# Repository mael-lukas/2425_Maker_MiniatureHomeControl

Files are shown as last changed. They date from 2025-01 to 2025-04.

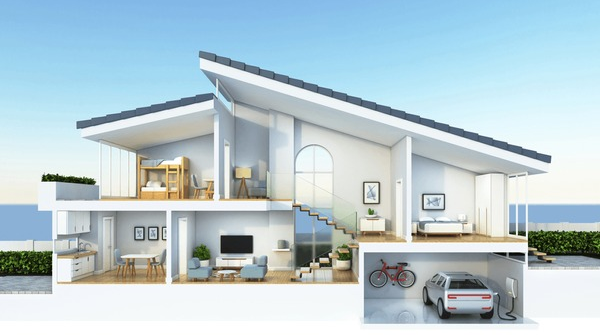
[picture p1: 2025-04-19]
Media/Design Inspirations/screen2.png

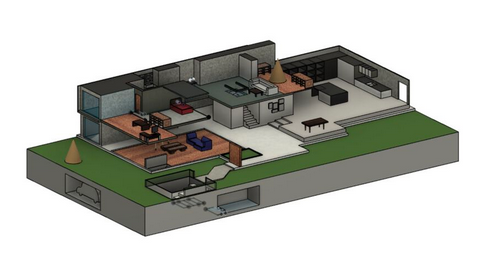
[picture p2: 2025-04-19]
Media/Design Inspirations/screen1.png

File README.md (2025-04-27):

Miniature Home control

Maker 2024-2025 - Miniature Home control
========================================

Project overview

Introduction
------------

This project was carried out as part of the Maker option at ENSEA. The idea was to create a miniature home that could house a small animal with a bunch of actuated parts  
(doors, lights, food dispenser...) that could be activated remotely.  
Design-wise the house is inspired by typical doll house designs and modern houses:



Below is the architectural diagram that sums up all the features that were to be included in the house at the start of the project:

CAD
---

This project involved a lot of CAD. A significant part was the modeling of the whole house. The goal was to make the house out of wood using the laser cutter.  
Thus the model needed to be able to be separated in several parts to be cut on a flat sheet



All the furnitures to be placed in the house were also 3D modeled by myself (except the chair I downloaded it online). They were then 3D printed.



PCB
---

Every PCBs in this project were designed on KiCAD and manufactured by JLCPCB.  
This project needed two PCBs: one main unit would be wired to every actuatable parts in the house.  
Thus, it is mainly comprised of sockets to wire to every motors, lights, TV...



The second PCB is the controller of the house to actuate remotely every part of the house. Thus it is mainly comprised of buttons to look like a run-of-the-mill remote:



Assembly
--------

After laser cutting the wood the house was assembled, some furnitures were also placed inside:



The assembly part also involved a lot of wiring. I made custom wires for the power supply to power the main unit, a LiPo battery for the controller  
and several wires for motors and lights in the house:



Programming
-----------

The code was written  in C language on STM32 CubeIDE. It is devised according to this diagram:



I wrote a working code for the LCD screen (for the TV), servo motors, Neopixel LEDs and the MP3 module. I did not have time to test the code for the HC-05 bluetooth module.  
The whole code can be found in the GitHub repository (as well as every other resources of the project)

Final word
----------

I did not have the time to finish the project so only the house, the PCBs and the lights and doors are implemented but I still had a great time doing this project and participating in Maker.

### Short video

Here is a short [video](https://www.youtube.com/watch?v=WIeOZKU2mvY&t=1s) (in French) to sum up the project and my views on the Maker option

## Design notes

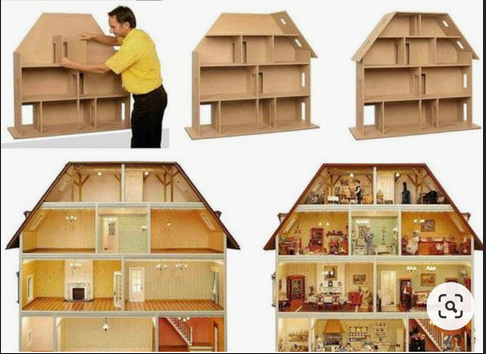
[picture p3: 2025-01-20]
Media/Design Inspirations/screen.png

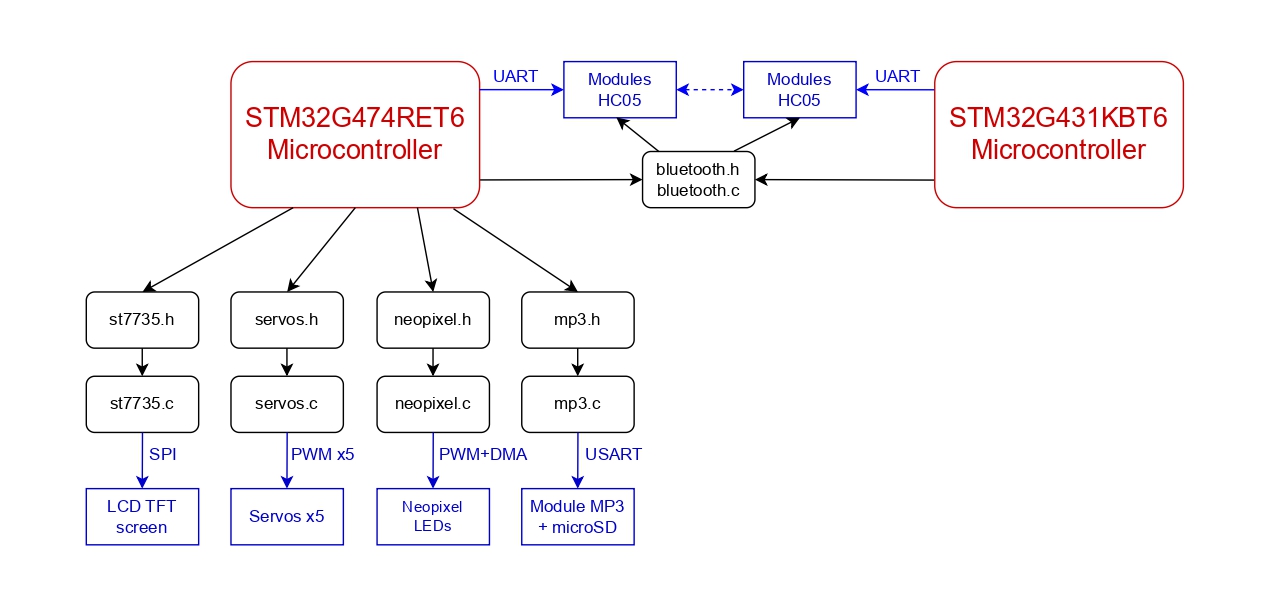
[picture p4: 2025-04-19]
Project Management/code architecture.jpg

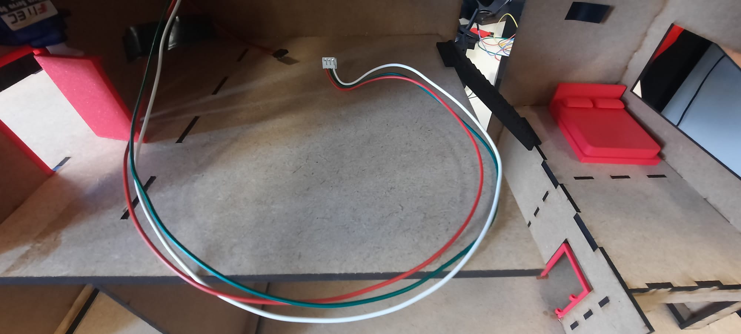
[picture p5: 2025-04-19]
Media/Project pictures/pic12.jpeg

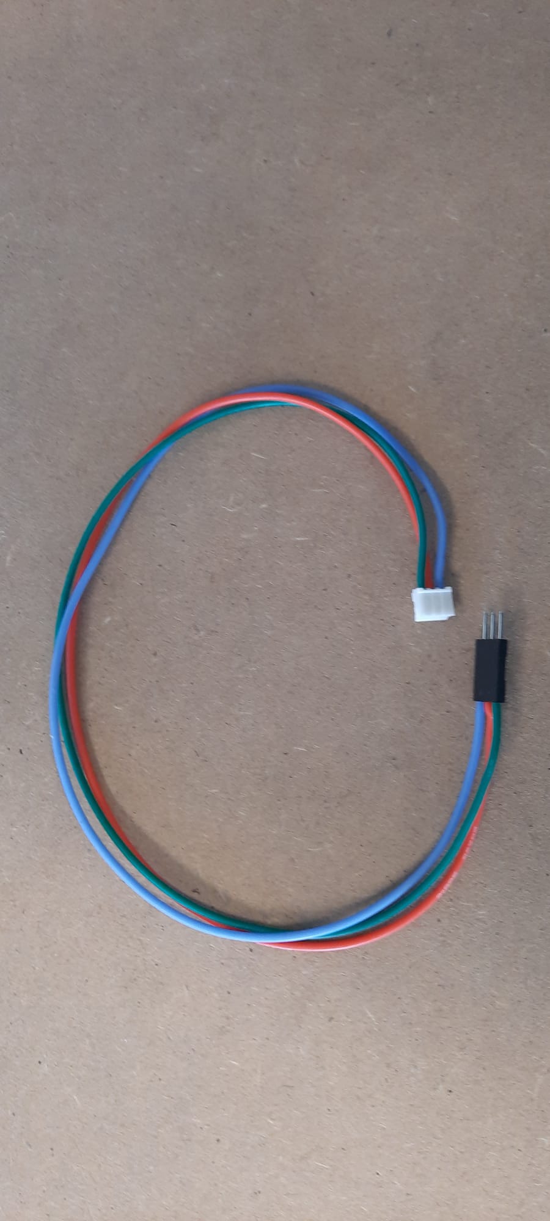
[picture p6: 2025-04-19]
Media/Project pictures/pic1.jpeg

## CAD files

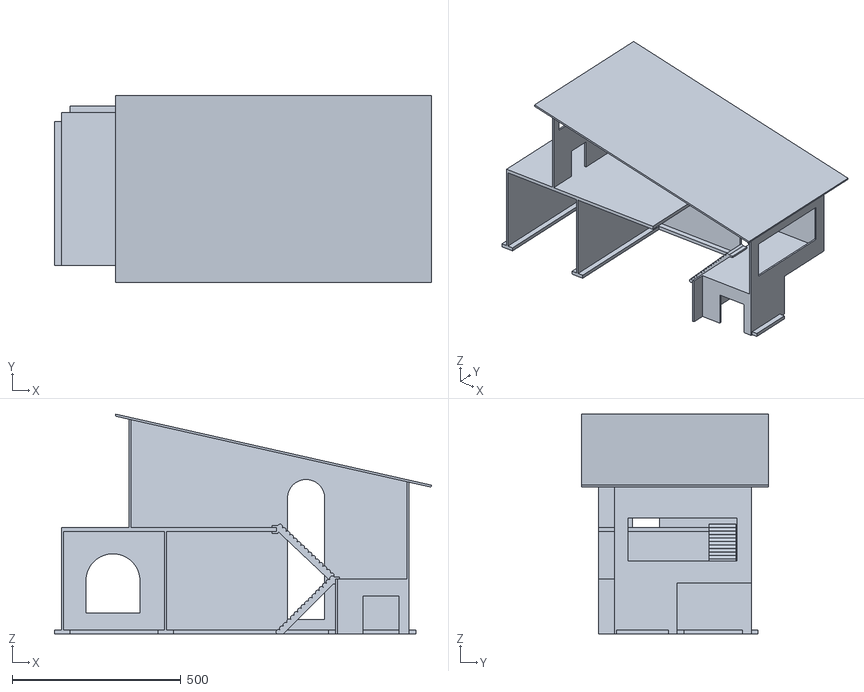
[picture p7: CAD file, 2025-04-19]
CAD/full_house.stl
1116.3 x 553.0 x 650.6

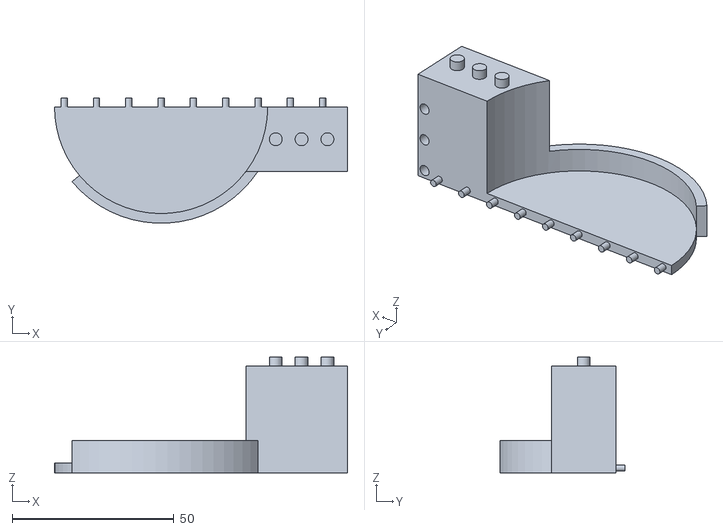
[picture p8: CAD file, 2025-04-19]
CAD/food_5.stl
90.7 x 38.8 x 35.8

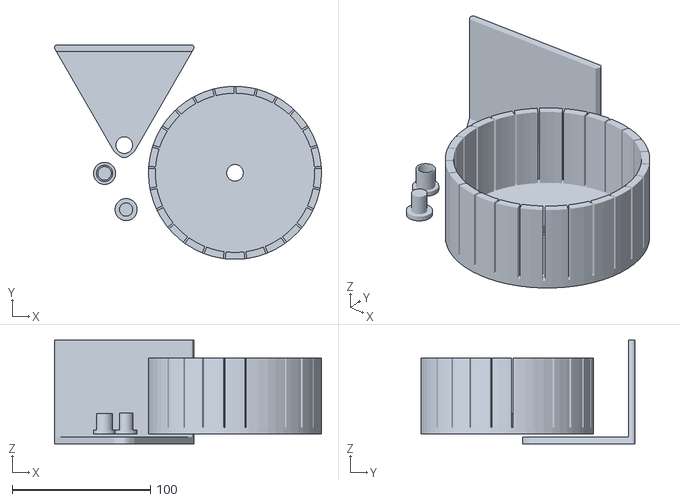
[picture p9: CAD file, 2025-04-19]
CAD/wheel.stl
192.9 x 154.9 x 75.0

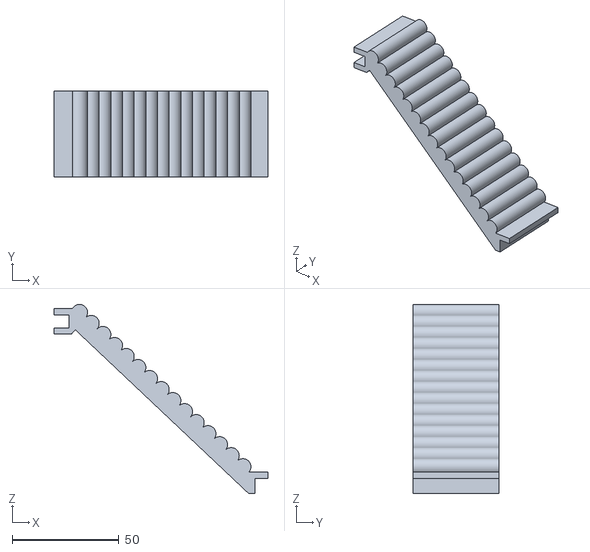
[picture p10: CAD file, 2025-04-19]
CAD/stairs_2.stl
100.0 x 40.0 x 88.4

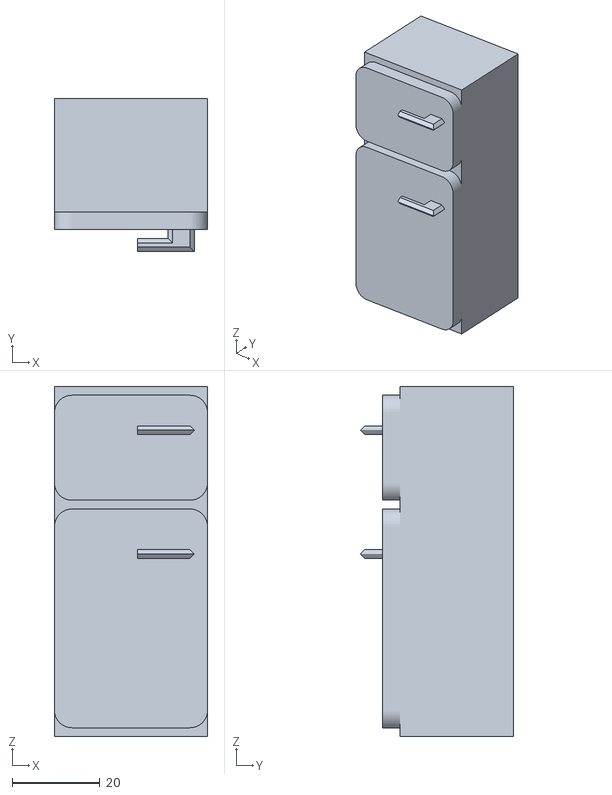
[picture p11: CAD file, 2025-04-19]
CAD/refridgator.stl
35.0 x 35.0 x 80.0

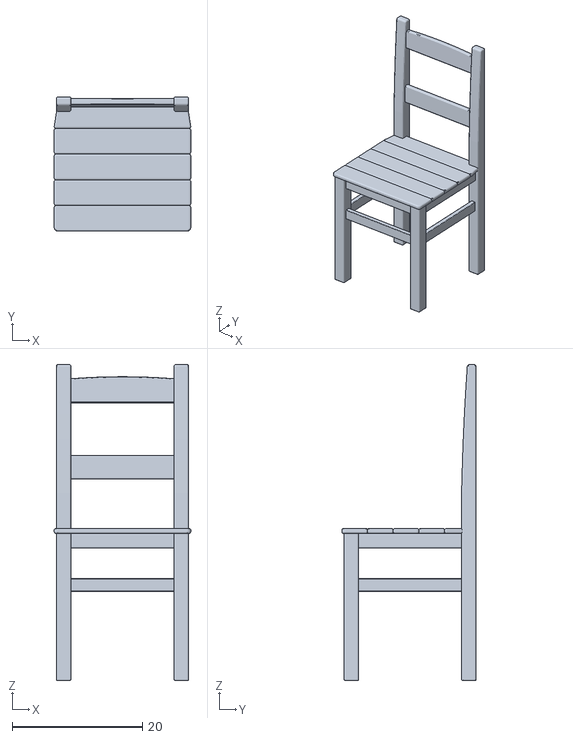
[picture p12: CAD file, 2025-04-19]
CAD/chair.stl
21.0 x 20.7 x 48.5

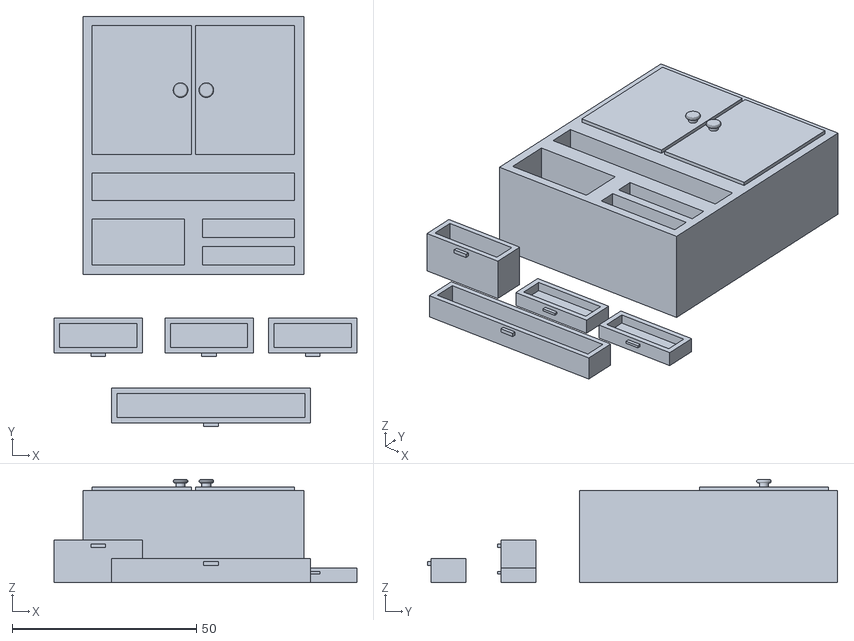
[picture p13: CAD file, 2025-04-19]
CAD/wardrobe.stl
82.2 x 111.3 x 28.0

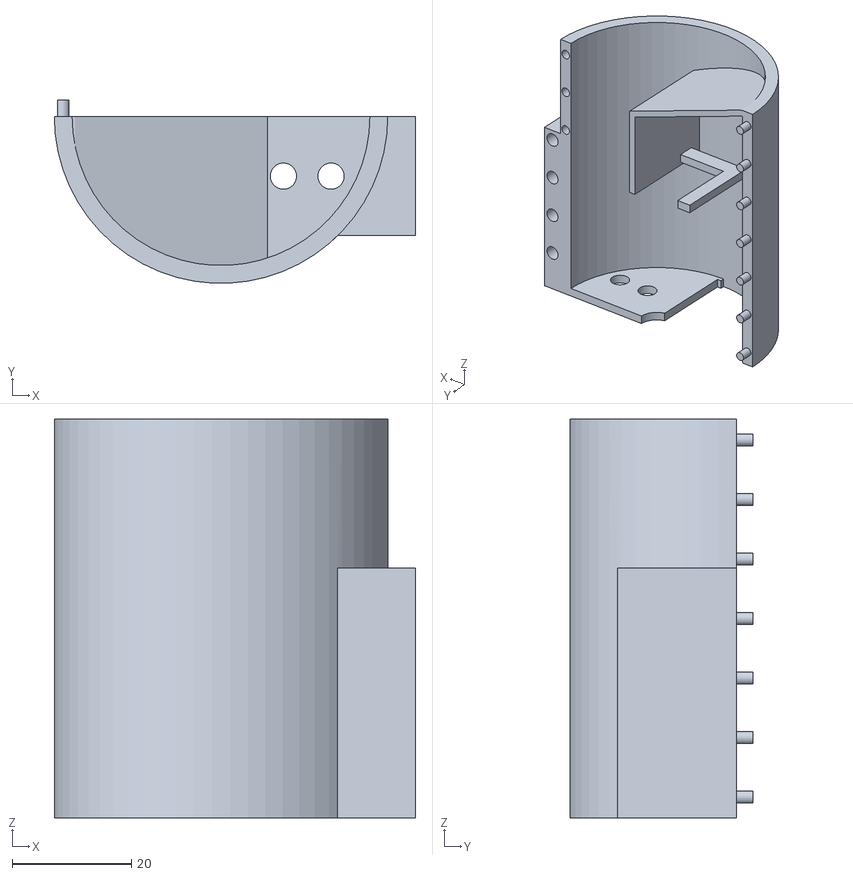
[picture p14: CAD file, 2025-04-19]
CAD/food_1.stl
60.7 x 30.8 x 67.0

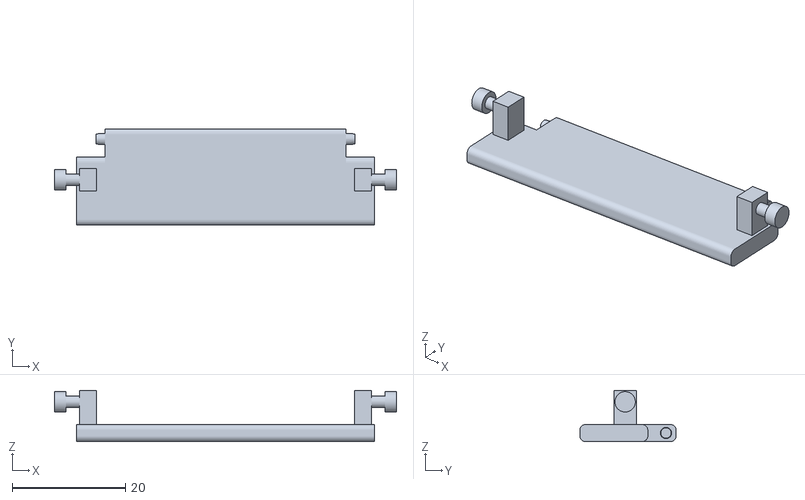
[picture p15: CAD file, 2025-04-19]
CAD/gdoor_2.stl
60.3 x 17.0 x 9.00

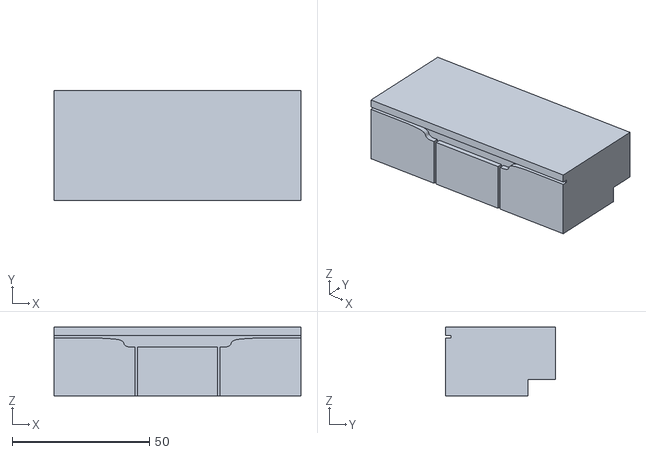
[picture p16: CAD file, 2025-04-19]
CAD/tv_drawer.stl
90.0 x 40.0 x 25.0

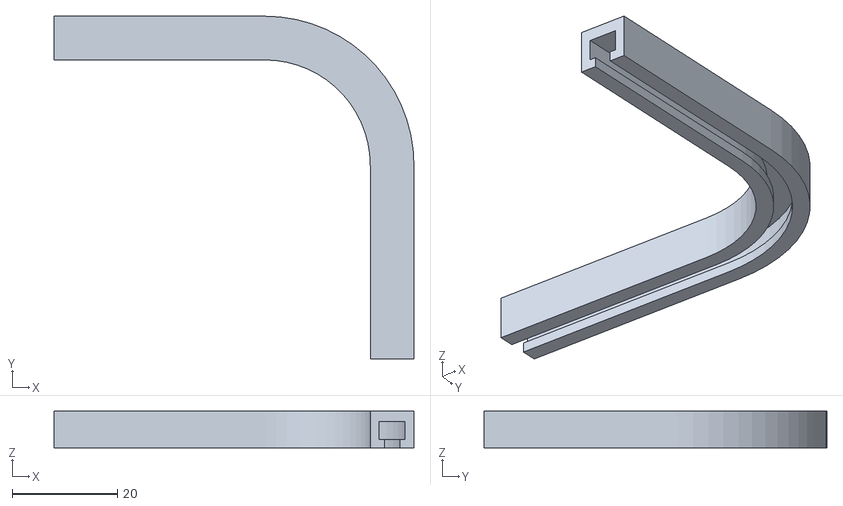
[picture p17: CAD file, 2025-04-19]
CAD/rail_2.stl
68.3 x 65.0 x 7.00

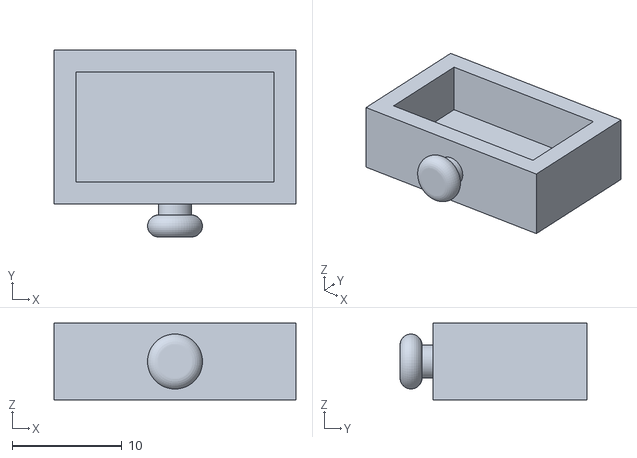
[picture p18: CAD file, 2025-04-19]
CAD/drawer_2.stl
22.0 x 17.0 x 7.00

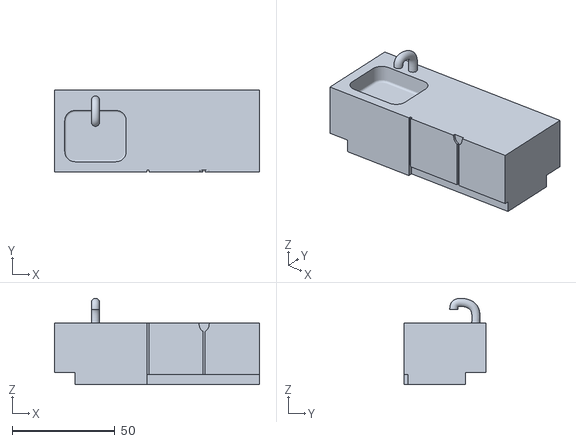
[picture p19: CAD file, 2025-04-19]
CAD/sink.stl
100.0 x 40.0 x 42.2

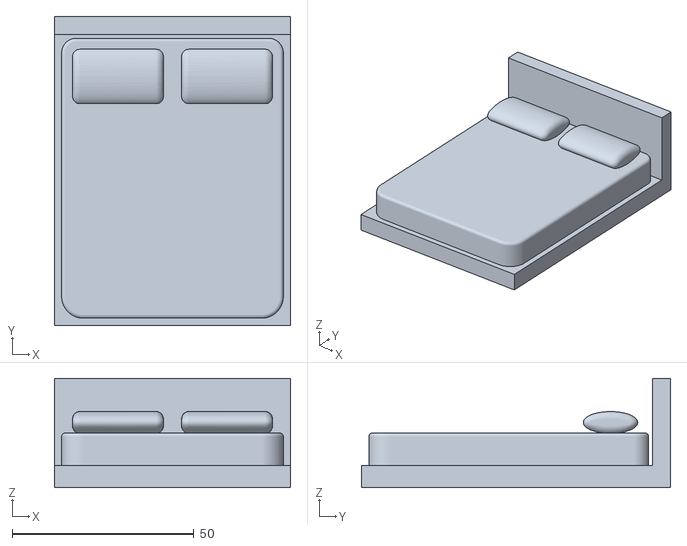
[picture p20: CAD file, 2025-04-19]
CAD/bed.stl
65.0 x 85.0 x 30.0

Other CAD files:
CAD/food_3.stl
CAD/door_1.stl
CAD/food_2.stl
CAD/gdoor_3.stl
CAD/door_2.stl
CAD/drawer_1.stl
CAD/food_4.stl
CAD/gdoor_1.stl
CAD/rail_1.stl
CAD/stairs_1.stl
CAD/table.stl

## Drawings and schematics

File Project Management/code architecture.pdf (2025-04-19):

## STM32G474RET6 Microcontroller

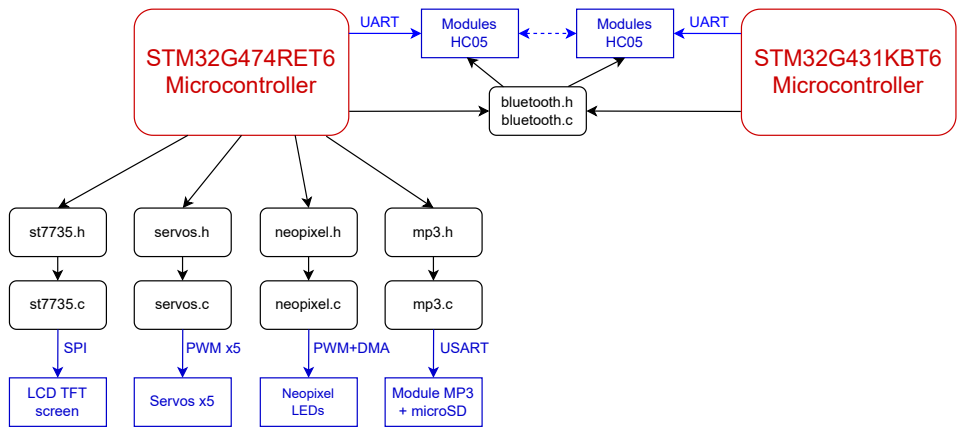
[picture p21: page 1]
LCD TFT screen; servos.h; servos.c; Servos x5; neopixel.h; neopixel.c; Neopixel LEDs; Module MP3 + microSD; SPI; PWM x5; PWM+DMA; USART; STM32G431KBT6 Microcontroller; Modules HC05; bluetooth.h bluetooth.c; UART

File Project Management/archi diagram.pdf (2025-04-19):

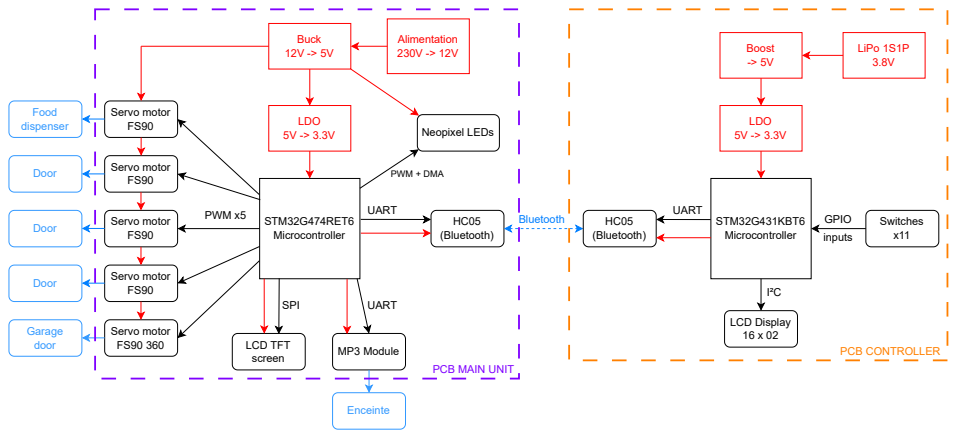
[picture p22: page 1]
STM32G474RET6 Microcontroller; Alimentation 230V -> 12V; Buck 12V -> 5V; LDO 5V -> 3.3V; Servo motor FS90; Servo motor FS90 360; LCD TFT screen; Neopixel LEDs; MP3 Module; Enceinte; HC05 (Bluetooth); PWM x5; PWM + DMA; SPI; UART; Food dispenser; Door; Garage door; Bluetooth; STM32G431KBT6; Microcontroller; LiPo 1S1P 3.8V; Boost -> 5V; Switches x11; GPIO; inputs; LCD Display 16 x 02; I²C; PCB CONTROLLER

PCB MAIN UNIT

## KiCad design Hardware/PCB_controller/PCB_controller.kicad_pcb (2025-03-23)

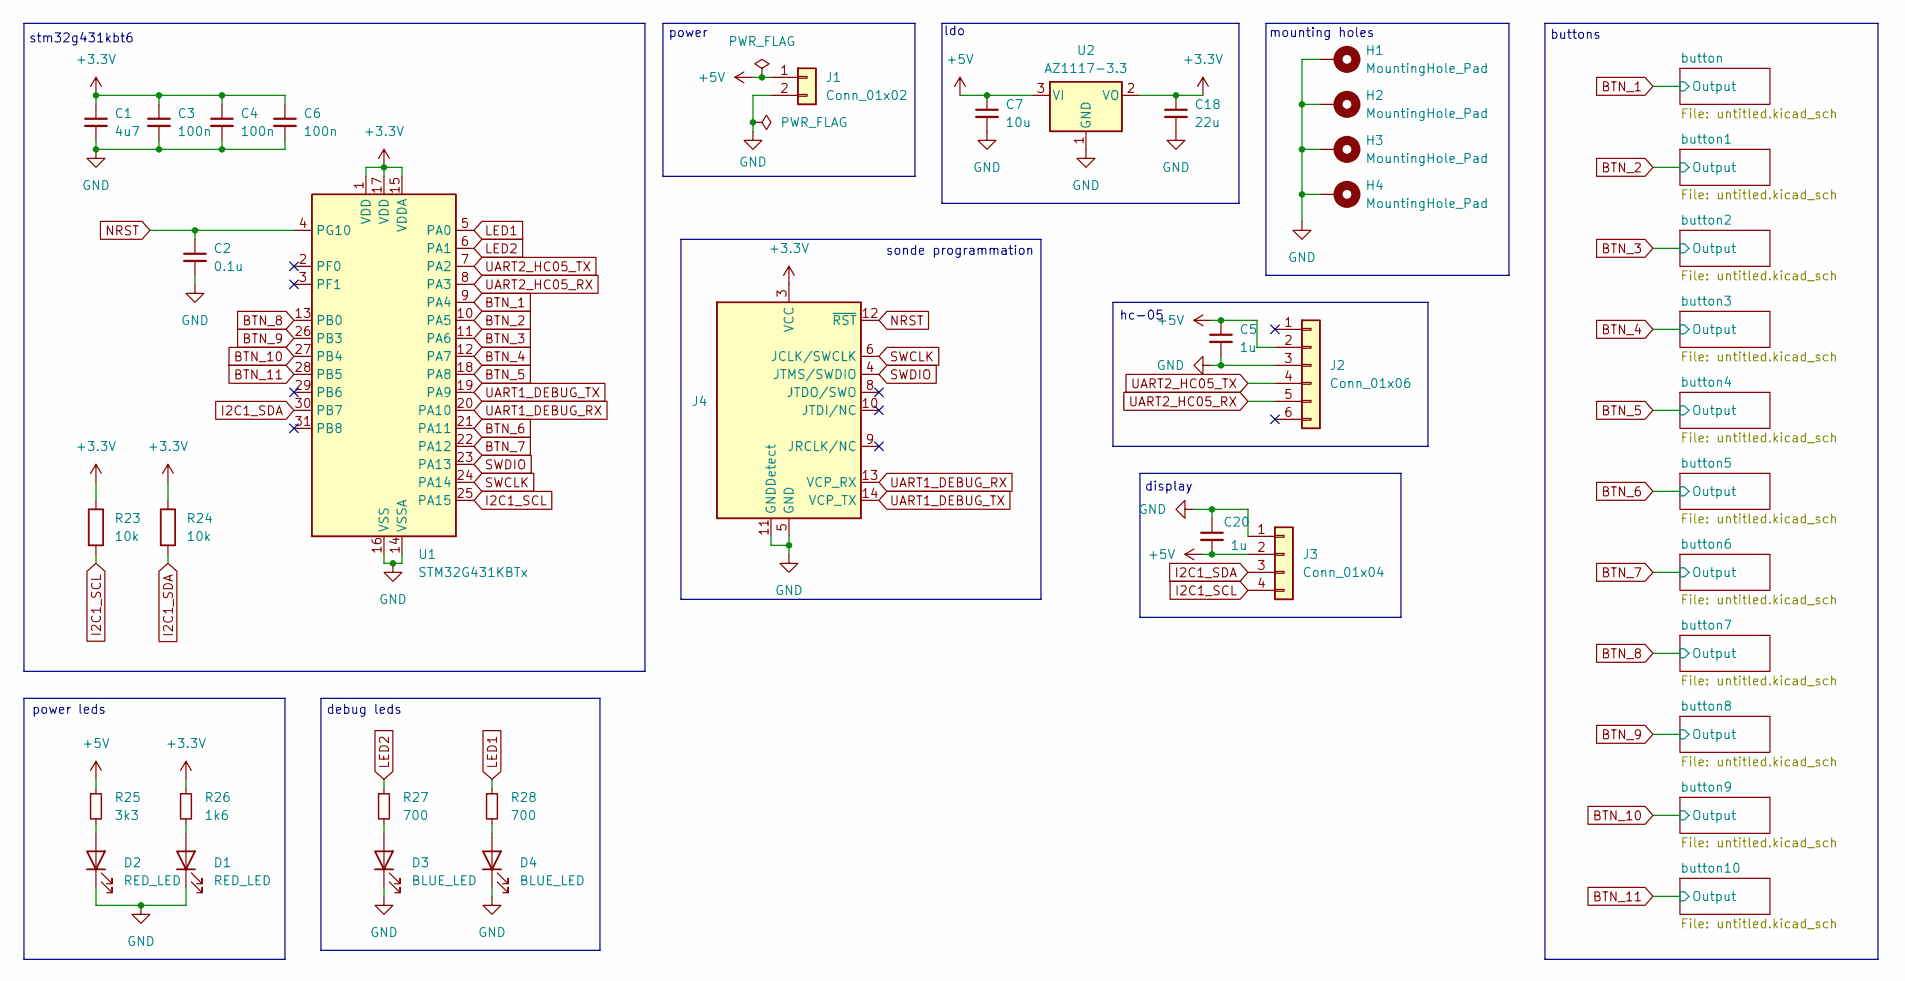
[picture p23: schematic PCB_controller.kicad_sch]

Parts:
C1: 4u7; C_0603_1608Metric
C2: 0.1u; C_0402_1005Metric_Pad0.74x0.62mm_HandSolder
C3, C4, C6: 100n; C_0402_1005Metric_Pad0.74x0.62mm_HandSolder
C5, C20: 1u; C_0603_1608Metric
C7: 10u; C_0603_1608Metric
C18: 22u; C_Elec_5x5.4
D1, D2: RED_LED; LED_0603_1608Metric; MPN 150060RS55040
D3, D4: BLUE_LED; LED_0603_1608Metric; MPN 150060BS55040
H1, H2, H3, H4: MountingHole_Pad; MountingHole_3.2mm_M3_Pad_Via
J1: Conn_01x02; JST_EH_B2B-EH-A_1x02_P2.50mm_Vertical
J2: Conn_01x06; JST_EH_B6B-EH-A_1x06_P2.50mm_Vertical
J3: Conn_01x04; JST_EH_B4B-EH-A_1x04_P2.50mm_Vertical
J4: Conn_ST_STDC14; PinHeader_2x07_P1.27mm_Vertical_SMD
R23, R24: 10k; R_0402_1005Metric_Pad0.72x0.64mm_HandSolder
R25: 3k3; R_0402_1005Metric_Pad0.72x0.64mm_HandSolder
R26: 1k6; R_0402_1005Metric_Pad0.72x0.64mm_HandSolder
R27, R28: 700; R_0402_1005Metric_Pad0.72x0.64mm_HandSolder
U1: STM32G431KBTx; LQFP-32_7x7mm_P0.8mm
U2: AZ1117-3.3; SOT-223-3_TabPin2; MPN AZ1117CH2-3.3TRG1

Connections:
+3.3V: C1.1, C3.1, C4.1, C6.1, C18.1, J4.3 (VCC), R23.1, R24.1, R26.1, U1.1 (VDD), U1.15 (VDDA), U1.17 (VDD), U2.2 (VO); also elsewhere on the board
+5V: C5.1, C7.1, C20.2, J1.1, J2.2, J3.2, R25.1, U2.3 (VI)
BTN_1: U1.9 (PA4); also elsewhere on the board
BTN_2: U1.10 (PA5); also elsewhere on the board
BTN_3: U1.11 (PA6); also elsewhere on the board
BTN_4: U1.12 (PA7); also elsewhere on the board
BTN_5: U1.18 (PA8); also elsewhere on the board
BTN_6: U1.21 (PA11); also elsewhere on the board
BTN_7: U1.22 (PA12); also elsewhere on the board
BTN_8: U1.13 (PB0); also elsewhere on the board
BTN_9: U1.26 (PB3); also elsewhere on the board
BTN_10: U1.27 (PB4); also elsewhere on the board
BTN_11: U1.28 (PB5); also elsewhere on the board
GND: C1.2, C2.2, C3.2, C4.2, C5.2, C6.2, C7.2, C18.2, C20.1, D1.1 (K), D2.1 (K), D3.1 (K), D4.1 (K), H1.1, H2.1, H3.1, H4.1, J1.2, J2.3, J3.1, J4.5 (GND), J4.7 (GND), J4.11 (GNDDetect), U1.14 (VSSA), U1.16 (VSS), U1.32 (VSS), U2.1 (GND); also elsewhere on the board
I2C1_SCL: J3.4, R23.2, U1.25 (PA15)
I2C1_SDA: J3.3, R24.2, U1.30 (PB7)
LED1: R28.1, U1.5 (PA0)
LED2: R27.1, U1.6 (PA1)
NRST: C2.1, J4.12 (~RST), U1.4 (PG10)
unnamed: D1.2 (A), R26.2
unnamed: D2.2 (A), R25.2
unnamed: D3.2 (A), R27.2
unnamed: D4.2 (A), R28.2
SWCLK: J4.6 (JCLK/SWCLK), U1.24 (PA14)
SWDIO: J4.4 (JTMS/SWDIO), U1.23 (PA13)
UART1_DEBUG_RX: J4.13 (VCP_RX), U1.20 (PA10)
UART1_DEBUG_TX: J4.14 (VCP_TX), U1.19 (PA9)
UART2_HC05_RX: J2.5, U1.8 (PA3)
UART2_HC05_TX: J2.4, U1.7 (PA2)

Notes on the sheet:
mounting holes
ldo
buttons
stm32g431kbt6
power
sonde programmation
debug leds
display
power leds
hc-05

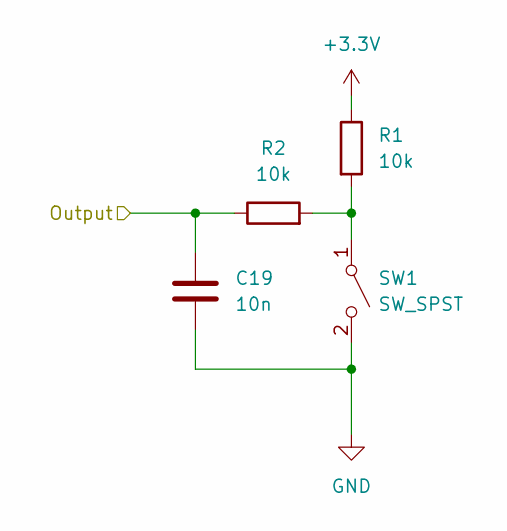
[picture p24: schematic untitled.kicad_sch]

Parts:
C19: 10n; C_0402_1005Metric_Pad0.74x0.62mm_HandSolder
R1, R2: 10k; R_0402_1005Metric_Pad0.72x0.64mm_HandSolder
SW1: SW_SPST; botan

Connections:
+3.3V: R1.1; also elsewhere on the board
BTN_1: C19.1, R2.1; also elsewhere on the board
GND: C19.2, SW1.2 (B); also elsewhere on the board
unnamed: R1.2, R2.2, SW1.1 (A)

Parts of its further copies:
C8, C9, C10, C11, C12, C13, C14, C15, C16, C17: 10n; C_0402_1005Metric_Pad0.74x0.62mm_HandSolder
R3, R4, R5, R6, R7, R8, R9, R10, R11, R12, R13, R14, R15, R16, R17, R18, R19, R20, R21, R22: 10k; R_0402_1005Metric_Pad0.72x0.64mm_HandSolder
SW2, SW3, SW4, SW5, SW6, SW7, SW8, SW9, SW10, SW11: SW_SPST; botan

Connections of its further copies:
+3.3V: R4.1, R6.1, R8.1, R10.1, R12.1, R14.1, R16.1, R18.1, R20.1, R22.1; also elsewhere on the board
BTN_2: C8.1, R3.1; also elsewhere on the board
BTN_3: C9.1, R5.1; also elsewhere on the board
BTN_4: C10.1, R7.1; also elsewhere on the board
BTN_5: C11.1, R9.1; also elsewhere on the board
BTN_6: C12.1, R11.1; also elsewhere on the board
BTN_7: C13.1, R13.1; also elsewhere on the board
BTN_8: C14.1, R15.1; also elsewhere on the board
BTN_9: C15.1, R17.1; also elsewhere on the board
BTN_10: C16.1, R19.1; also elsewhere on the board
BTN_11: C17.1, R21.1; also elsewhere on the board
GND: C8.2, C9.2, C10.2, C11.2, C12.2, C13.2, C14.2, C15.2, C16.2, C17.2, SW2.2 (B), SW3.2 (B), SW4.2 (B), SW5.2 (B), SW6.2 (B), SW7.2 (B), SW8.2 (B), SW9.2 (B), SW10.2 (B), SW11.2 (B); also elsewhere on the board
unnamed: R3.2, R4.2, SW2.1 (A)
unnamed: R5.2, R6.2, SW3.1 (A)
unnamed: R7.2, R8.2, SW4.1 (A)
unnamed: R9.2, R10.2, SW5.1 (A)
unnamed: R11.2, R12.2, SW6.1 (A)
unnamed: R13.2, R14.2, SW7.1 (A)
unnamed: R15.2, R16.2, SW8.1 (A)
unnamed: R17.2, R18.2, SW9.1 (A)
unnamed: R19.2, R20.2, SW10.1 (A)
unnamed: R21.2, R22.2, SW11.1 (A)

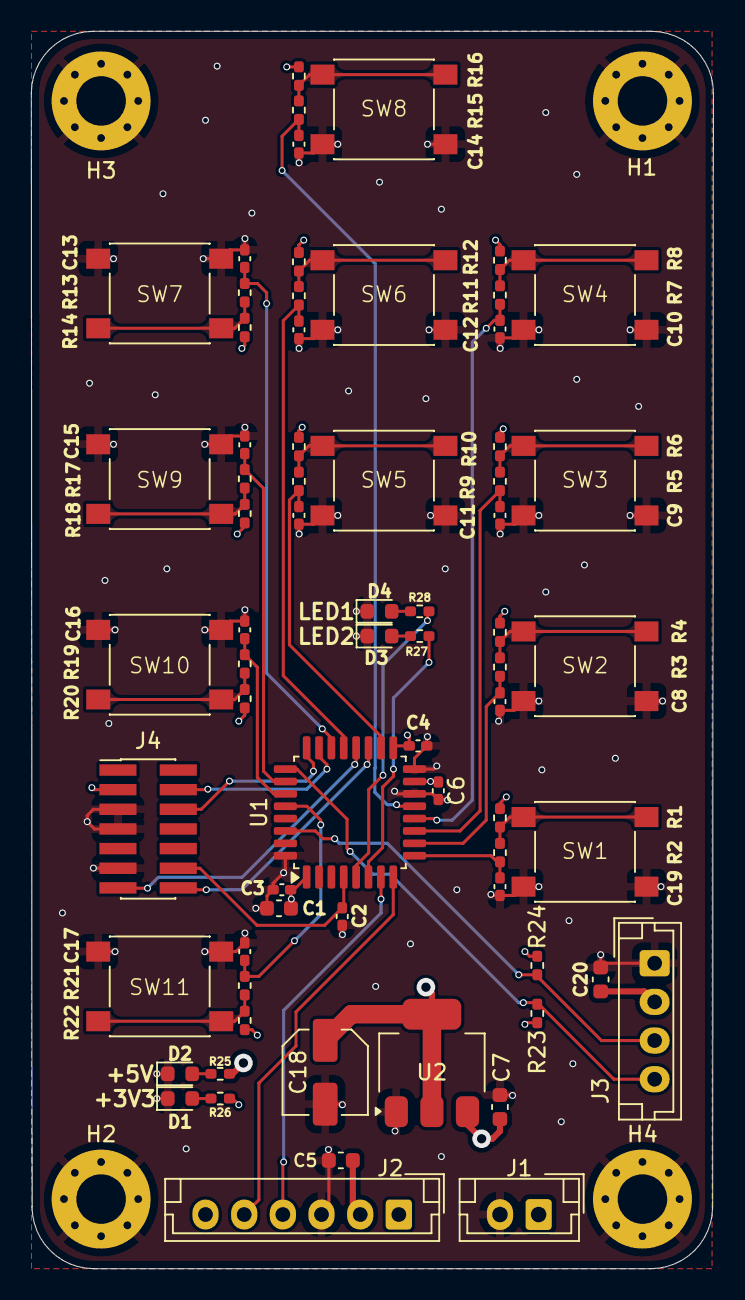
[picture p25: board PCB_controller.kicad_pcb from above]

Board: 4 copper layers, 44.1 x 80.0 mm, 73 parts (0 on the bottom side), 40 nets.

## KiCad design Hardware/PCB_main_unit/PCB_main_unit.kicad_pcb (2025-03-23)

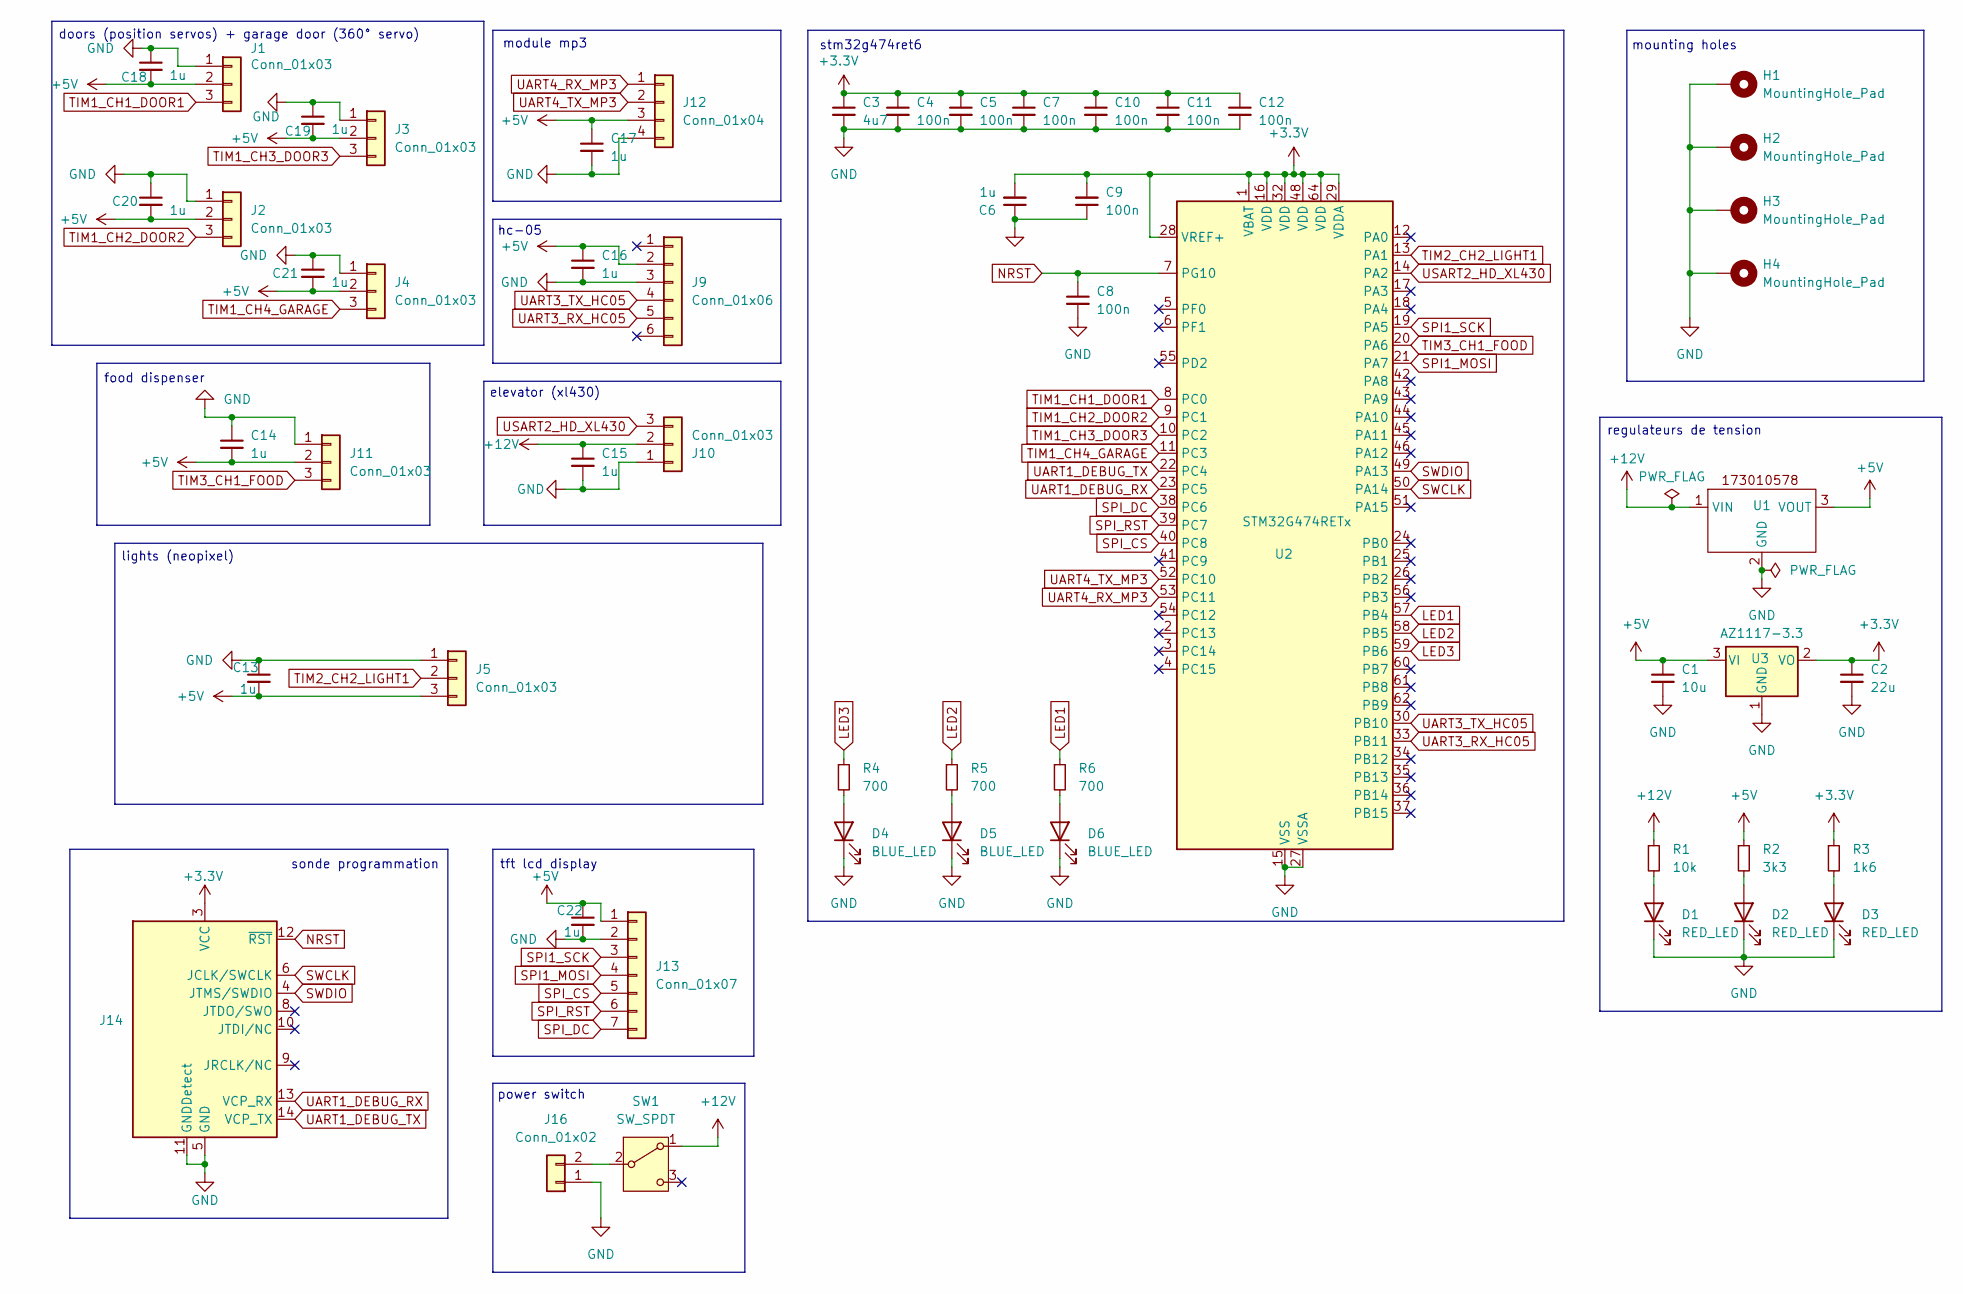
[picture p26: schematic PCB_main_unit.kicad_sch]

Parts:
C1: 10u; C_0603_1608Metric
C2: 22u; C_Elec_5x5.4
C3: 4u7; C_0603_1608Metric
C4, C5, C7, C8, C9, C10, C11, C12: 100n; C_0402_1005Metric_Pad0.74x0.62mm_HandSolder
C6, C13, C14, C15, C16, C17, C18, C19, C20, C21, C22: 1u; C_0603_1608Metric
D1, D2, D3: RED_LED; LED_0603_1608Metric; MPN 150060RS55040
D4, D5, D6: BLUE_LED; LED_0603_1608Metric; MPN 150060BS55040
H1, H2, H3, H4: MountingHole_Pad; MountingHole_3.2mm_M3_Pad_Via
J1, J2, J3, J4, J5, J10, J11: Conn_01x03; JST_EH_B3B-EH-A_1x03_P2.50mm_Vertical
J9: Conn_01x06; JST_EH_B6B-EH-A_1x06_P2.50mm_Vertical
J12: Conn_01x04; JST_EH_B4B-EH-A_1x04_P2.50mm_Vertical
J13: Conn_01x07; JST_EH_B7B-EH-A_1x07_P2.50mm_Vertical
J14: Conn_ST_STDC14; PinHeader_2x07_P1.27mm_Vertical_SMD
J16: Conn_01x02; AMASS_XT60-M_1x02_P7.20mm_Vertical
R1: 10k; R_0402_1005Metric_Pad0.72x0.64mm_HandSolder
R2: 3k3; R_0402_1005Metric_Pad0.72x0.64mm_HandSolder
R3: 1k6; R_0402_1005Metric_Pad0.72x0.64mm_HandSolder
R4, R5, R6: 700; R_0402_1005Metric_Pad0.72x0.64mm_HandSolder
SW1: SW_SPDT; power_switch; MPN 472123010111
U1: 173010578; MPN 173010578
U2: STM32G474RETx; LQFP-64_10x10mm_P0.5mm
U3: AZ1117-3.3; SOT-223-3_TabPin2; MPN AZ1117CH2-3.3TRG1

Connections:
+3.3V: C2.1, C3.1, C4.1, C5.1, C6.2, C7.1, C9.2, C10.1, C11.1, C12.1, J14.3 (VCC), R3.1, U2.1 (VBAT), U2.16 (VDD), U2.28 (VREF+), U2.29 (VDDA), U2.32 (VDD), U2.48 (VDD), U2.64 (VDD), U3.2 (VO)
+5V: C1.1, C13.2, C14.2, C16.1, C17.1, C18.2, C19.2, C20.2, C21.2, C22.1, J1.2, J2.2, J3.2, J4.2, J5.3, J9.2, J11.2, J12.3, J13.1, R2.1, U1.3 (VOUT), U3.3 (VI)
+12V: C15.1, J10.2, R1.1, SW1.1 (A), U1.1 (VIN)
GND: C1.2, C2.2, C3.2, C4.2, C5.2, C6.1, C7.2, C8.2, C9.1, C10.2, C11.2, C12.2, C13.1, C14.1, C15.2, C16.2, C17.2, C18.1, C19.1, C20.1, C21.1, C22.2, D1.1 (K), D2.1 (K), D3.1 (K), D4.1 (K), D5.1 (K), D6.1 (K), H1.1, H2.1, H3.1, H4.1, J1.1, J2.1, J3.1, J4.1, J5.1, J9.3, J10.1, J11.1, J12.4, J13.2, J14.5 (GND), J14.7 (GND), J14.11 (GNDDetect), J16.1, U1.2 (GND), U2.15 (VSS), U2.27 (VSSA), U2.31 (VSS), U2.47 (VSS), U2.63 (VSS), U3.1 (GND)
LED1: R6.1, U2.57 (PB4)
LED2: R5.1, U2.58 (PB5)
LED3: R4.1, U2.59 (PB6)
NRST: C8.1, J14.12 (~RST), U2.7 (PG10)
unnamed: D1.2 (A), R1.2
unnamed: D2.2 (A), R2.2
unnamed: D3.2 (A), R3.2
unnamed: D4.2 (A), R4.2
unnamed: D5.2 (A), R5.2
unnamed: D6.2 (A), R6.2
unnamed: J16.2, SW1.2 (B)
SPI1_MOSI: J13.4, U2.21 (PA7)
SPI1_SCK: J13.3, U2.19 (PA5)
SPI_CS: J13.5, U2.40 (PC8)
SPI_DC: J13.7, U2.38 (PC6)
SPI_RST: J13.6, U2.39 (PC7)
SWCLK: J14.6 (JCLK/SWCLK), U2.50 (PA14)
SWDIO: J14.4 (JTMS/SWDIO), U2.49 (PA13)
TIM1_CH1_DOOR1: J1.3, U2.8 (PC0)
TIM1_CH2_DOOR2: J2.3, U2.9 (PC1)
TIM1_CH3_DOOR3: J3.3, U2.10 (PC2)
TIM1_CH4_GARAGE: J4.3, U2.11 (PC3)
TIM2_CH2_LIGHT1: J5.2, U2.13 (PA1)
TIM3_CH1_FOOD: J11.3, U2.20 (PA6)
UART1_DEBUG_RX: J14.13 (VCP_RX), U2.23 (PC5)
UART1_DEBUG_TX: J14.14 (VCP_TX), U2.22 (PC4)
UART3_RX_HC05: J9.5, U2.33 (PB11)
UART3_TX_HC05: J9.4, U2.30 (PB10)
UART4_RX_MP3: J12.1, U2.53 (PC11)
UART4_TX_MP3: J12.2, U2.52 (PC10)
USART2_HD_XL430: J10.3, U2.14 (PA2)

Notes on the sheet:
elevator (xl430)
tft lcd display
doors (position servos) + garage door (360° servo)
hc-05
stm32g474ret6
lights (neopixel)
sonde programmation
module mp3
food dispenser
power switch
mounting holes
regulateurs de tension

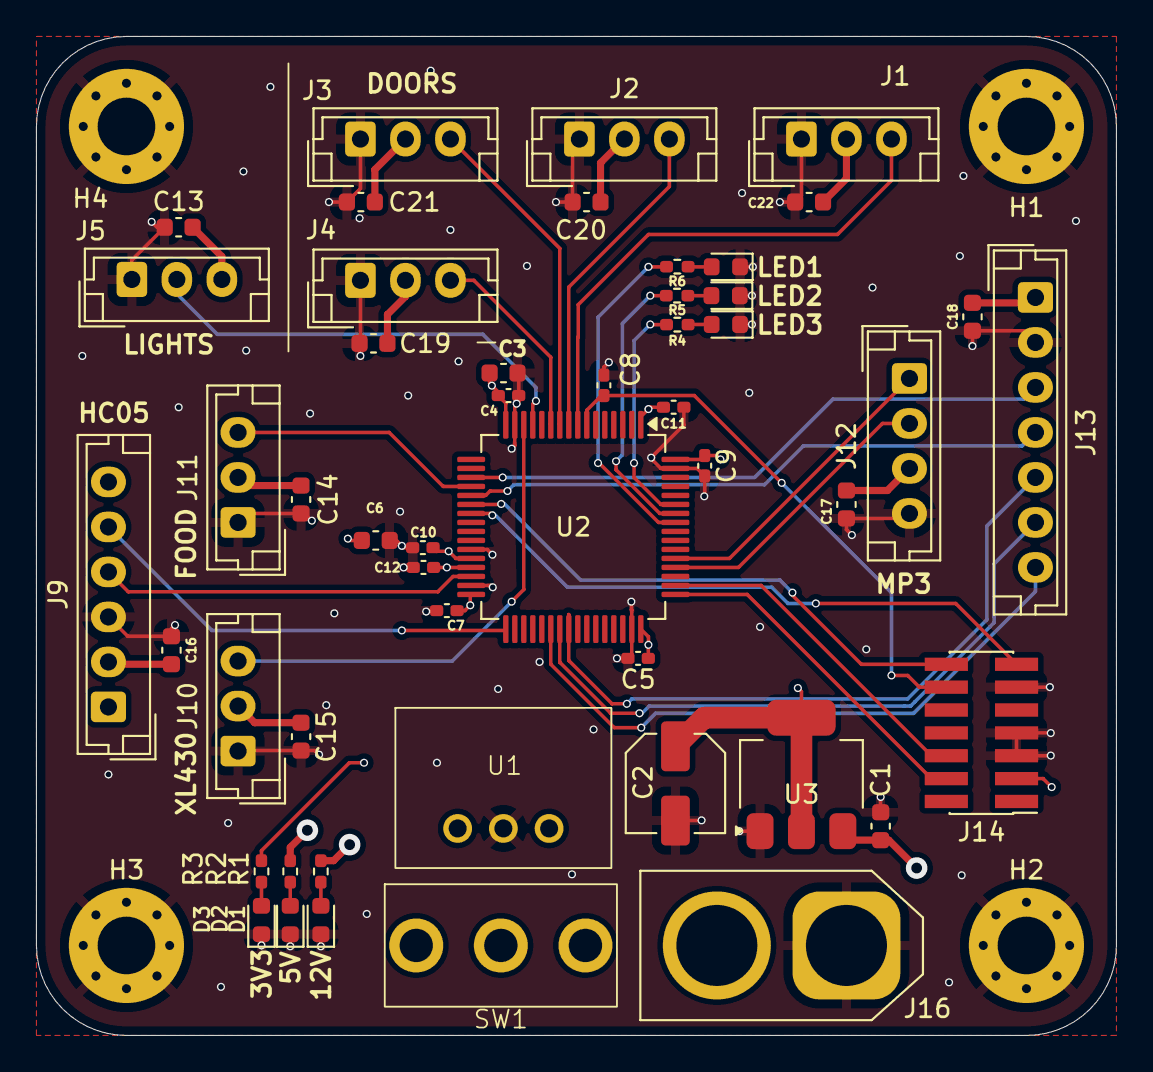
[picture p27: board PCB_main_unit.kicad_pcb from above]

Board: 4 copper layers, 60.0 x 55.5 mm, 54 parts (0 on the bottom side), 35 nets.

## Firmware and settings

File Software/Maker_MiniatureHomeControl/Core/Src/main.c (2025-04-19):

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
/* Includes ------------------------------------------------------------------*/
#include "main.h"
#include "dma.h"
#include "spi.h"
#include "tim.h"
#include "usart.h"
#include "gpio.h"

/* USER CODE BEGIN Includes */
#include "fonts.h"
#include "st7735.h"
#include "rat_dance.h"
#include "neopixel.h"
#include "servos.h"
#include "mp3.h"
#include "bluetooth_protocol.h"

/* USER CODE END Includes */


void SystemClock_Config(void);
/* USER CODE BEGIN 0 */
#ifdef __GNUC__
#define PUTCHAR_PROTOTYPE int __io_putchar(int ch)
#define GETCHAR_PROTOTYPE int __io_getchar(void)
#else
#define PUTCHAR_PROTOTYPE int fputc(int ch, FILE *f)
#define GETCHAR_PROTOTYPE int fgetc(FILE *f)
#endif

PUTCHAR_PROTOTYPE {
    HAL_UART_Transmit(&huart2, (uint8_t *)&ch, 1, HAL_MAX_DELAY);
    return ch;
}

GETCHAR_PROTOTYPE
{
	uint8_t ch = 0;

	/* Clear the Overrun flag just before receiving the first character */
	__HAL_UART_CLEAR_OREFLAG(&huart2);

	/* Wait for reception of a character on the USART RX line and echo this
	 * character on console */
	HAL_UART_Receive(&huart2, (uint8_t *)&ch, 1, HAL_MAX_DELAY);
	HAL_UART_Transmit(&huart2, (uint8_t *)&ch, 1, HAL_MAX_DELAY);
	return ch;
}


///////////////////////////////////////////////////////// BLUETOOTH PROTOCOL //////////////////////////////////////////////////////////////////////
char startChar = '@';
char endChar = '#';

uint8_t rx_char; // Variable to store the received character

char instruction[200];
int instructionIndex = 0;

int UARTReceiverState = 0;

volatile int flagUART1 = 0;


void HAL_UART_RxCpltCallback(UART_HandleTypeDef *huart) {
	// Re-enable UART interrupt reception
	HAL_UART_Receive_IT(&huart3, &rx_char, 1);

	instruction[instructionIndex] = rx_char;
	instructionIndex++;

	if (rx_char == '#')
	{
		instruction[instructionIndex] = 0; // 0 character for the printf
		instructionIndex = 0;
		flagUART1 = 1;
	}
}

/* USER CODE END 0 */

/**
  * @brief  The application entry point.
  * @retval int
  */
int main(void)
{

  /* MCU Configuration--------------------------------------------------------*/

  /* Reset of all peripherals, Initializes the Flash interface and the Systick. */
  HAL_Init();

  /* Configure the system clock */
  SystemClock_Config();

  /* Initialize all configured peripherals */
  MX_GPIO_Init();
  MX_DMA_Init();
  MX_USART1_UART_Init();
  MX_SPI1_Init();
  MX_TIM1_Init();
  MX_TIM2_Init();
  MX_TIM3_Init();
  MX_UART4_Init();
  MX_USART2_UART_Init();
  MX_USART3_UART_Init();

  /* USER CODE BEGIN 2 */

///////////////////////////////////////////////////////////// MP3 PLAYER //////////////////////////////////////////////////////////////////////////
  	mp3_selectStorageDevice();
  	waitNms(20);
  	mp3_setVolume(10);
  	waitNms(20);
  	mp3_playWithIndex(2);


///////////////////////////////////////////////////////////// NEOPIXEL ////////////////////////////////////////////////////////////////////////////
  animateBlink(0xFF0000,2500);


///////////////////////////////////////////////////////////// SERVO MOTORS ////////////////////////////////////////////////////////////////////////////
  h_servo_t servo1;
  servoInit(&servo1,&htim1,TIM_CHANNEL_4);
  turnServo(&servo1);
  HAL_Delay(1000);
  turnServo(&servo1);
  HAL_Delay(1000);


//////////////////////////////////////////////////////////// SPI SCREEN ///////////////////////////////////////////////////////////////////////////
  ST7735_Init();
  ST7735_FillScreen(ST7735_BLACK);
  ST7735_WriteString(0,0,"Hello World !",Font_7x10,ST7735_WHITE,ST7735_BLACK);
  HAL_Delay(300);

  /* USER CODE END 2 */

  /* Infinite loop */
  /* USER CODE BEGIN WHILE */
  while (1)
  {
	  ST7735_DrawImage(0, 0, ST7735_WIDTH, ST7735_HEIGHT, rd_frame00);
	  HAL_Delay(33);
	  ST7735_DrawImage(0, 0, ST7735_WIDTH, ST7735_HEIGHT, rd_frame01);
	  HAL_Delay(33);
	  ST7735_DrawImage(0, 0, ST7735_WIDTH, ST7735_HEIGHT, rd_frame02);
	  HAL_Delay(33);
	  ST7735_DrawImage(0, 0, ST7735_WIDTH, ST7735_HEIGHT, rd_frame03);
	  HAL_Delay(33);
	  ST7735_DrawImage(0, 0, ST7735_WIDTH, ST7735_HEIGHT, rd_frame04);
	  HAL_Delay(33);
	  ST7735_DrawImage(0, 0, ST7735_WIDTH, ST7735_HEIGHT, rd_frame05);
	  HAL_Delay(33);
	  ST7735_DrawImage(0, 0, ST7735_WIDTH, ST7735_HEIGHT, rd_frame06);
	  HAL_Delay(33);
	  ST7735_DrawImage(0, 0, ST7735_WIDTH, ST7735_HEIGHT, rd_frame07);
	  HAL_Delay(33);
	  ST7735_DrawImage(0, 0, ST7735_WIDTH, ST7735_HEIGHT, rd_frame08);
	  HAL_Delay(33);
	  ST7735_DrawImage(0, 0, ST7735_WIDTH, ST7735_HEIGHT, rd_frame09);
	  HAL_Delay(33);
	  ST7735_DrawImage(0, 0, ST7735_WIDTH, ST7735_HEIGHT, rd_frame10);
	  HAL_Delay(33);
	  ST7735_DrawImage(0, 0, ST7735_WIDTH, ST7735_HEIGHT, rd_frame11);
	  HAL_Delay(33);
	  ST7735_DrawImage(0, 0, ST7735_WIDTH, ST7735_HEIGHT, rd_frame12);
	  HAL_Delay(33);
	  ST7735_DrawImage(0, 0, ST7735_WIDTH, ST7735_HEIGHT, rd_frame13);
	  HAL_Delay(33);
	  ST7735_DrawImage(0, 0, ST7735_WIDTH, ST7735_HEIGHT, rd_frame14);
	  HAL_Delay(33);
	  ST7735_DrawImage(0, 0, ST7735_WIDTH, ST7735_HEIGHT, rd_frame15);
	  HAL_Delay(33);
	  ST7735_DrawImage(0, 0, ST7735_WIDTH, ST7735_HEIGHT, rd_frame16);
	  HAL_Delay(33);
	  ST7735_DrawImage(0, 0, ST7735_WIDTH, ST7735_HEIGHT, rd_frame17);
	  HAL_Delay(33);
	  ST7735_DrawImage(0, 0, ST7735_WIDTH, ST7735_HEIGHT, rd_frame18);
	  HAL_Delay(33);
	  ST7735_DrawImage(0, 0, ST7735_WIDTH, ST7735_HEIGHT, rd_frame19);
	  HAL_Delay(33);
	  ST7735_DrawImage(0, 0, ST7735_WIDTH, ST7735_HEIGHT, rd_frame20);
	  HAL_Delay(33);
	  ST7735_DrawImage(0, 0, ST7735_WIDTH, ST7735_HEIGHT, rd_frame21);
	  HAL_Delay(33);

    /* USER CODE END WHILE */

    /* USER CODE BEGIN 3 */
  }
  /* USER CODE END 3 */
}

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


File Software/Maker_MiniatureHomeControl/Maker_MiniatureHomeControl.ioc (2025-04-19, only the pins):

Mcu.UserName=STM32G474RETx
PA1.GPIO_Label=TIM2_CH2 (light1)
PA1.Signal=S_TIM2_CH2
PA13.Signal=SYS_JTMS-SWDIO
PA14.Signal=SYS_JTCK-SWCLK
PA2.GPIO_Label=USART2_TX (xl430)
PA2.Signal=USART2_TX
PA5.Signal=SPI1_SCK
PA6.GPIO_Label=TIM3_CH1 (food)
PA6.Signal=S_TIM3_CH1
PA7.Signal=SPI1_MOSI
PB10.GPIO_Label=USART3_TX (hc05)
PB10.Signal=USART3_TX
PB11.GPIO_Label=USART3_RX (hc05)
PB11.Signal=USART3_RX
PB4.GPIO_Label=LED1
PB4.Signal=GPIO_Output
PB5.GPIO_Label=LED2
PB5.Signal=GPIO_Output
PB6.GPIO_Label=LED3
PB6.Signal=GPIO_Output
PC0.GPIO_Label=TIM1_CH1 (door1)
PC0.Signal=S_TIM1_CH1
PC1.GPIO_Label=TIM1_CH2 (door2)
PC1.Signal=S_TIM1_CH2
PC10.GPIO_Label=UART4_TX (mp3)
PC10.Signal=UART4_TX
PC11.GPIO_Label=UART4_RX (mp3)
PC11.Signal=UART4_RX
PC2.GPIO_Label=TIM1_CH3 (door3)
PC2.Signal=S_TIM1_CH3
PC3.GPIO_Label=TIM1_CH4 (garage)
PC3.Signal=S_TIM1_CH4
PC4.GPIO_Label=USART1_TX (sonde)
PC4.Signal=USART1_TX
PC5.GPIO_Label=USART1_RX (sonde)
PC5.Signal=USART1_RX
PC6.GPIO_Label=SPI_DC
PC6.Signal=GPIO_Output
PC7.GPIO_Label=SPI_RST
PC7.Signal=GPIO_Output
PC8.GPIO_Label=SPI_CS
PC8.Signal=GPIO_Output

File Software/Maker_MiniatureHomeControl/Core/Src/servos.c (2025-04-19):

/*
 * servos.c
 *
 *  Created on: Apr 7, 2025
 *      Author: administrateur
 */

#include "servos.h"

void servoInit(h_servo_t *servoHandle, TIM_HandleTypeDef *timer, uint32_t timerChannel) {
	servoHandle->timer = timer;
	servoHandle->timerChannel = timerChannel;
	servoHandle->pos0 = 500;
	servoHandle->pos1 = 850;
	HAL_TIM_PWM_Start(servoHandle->timer, servoHandle->timerChannel);
	__HAL_TIM_SET_COMPARE(servoHandle->timer, servoHandle->timerChannel, servoHandle->pos0);
	servoHandle->currentPos = 0;
}

void turnServo(h_servo_t *servoHandle) {
	if (servoHandle->currentPos == 0) {
		__HAL_TIM_SET_COMPARE(servoHandle->timer, servoHandle->timerChannel, servoHandle->pos1);
	}
	if (servoHandle->currentPos == 1) {
		__HAL_TIM_SET_COMPARE(servoHandle->timer, servoHandle->timerChannel, servoHandle->pos0);
	}
	servoHandle->currentPos = 1 - servoHandle->currentPos;
}

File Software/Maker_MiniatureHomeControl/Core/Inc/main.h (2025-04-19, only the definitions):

#define TIM1_CH1_Pin GPIO_PIN_0
#define TIM1_CH1_GPIO_Port GPIOC
#define TIM1_CH2_Pin GPIO_PIN_1
#define TIM1_CH2_GPIO_Port GPIOC
#define TIM1_CH3_Pin GPIO_PIN_2
#define TIM1_CH3_GPIO_Port GPIOC
#define TIM1_CH4_Pin GPIO_PIN_3
#define TIM1_CH4_GPIO_Port GPIOC
#define TIM2_CH2_Pin GPIO_PIN_1
#define TIM2_CH2_GPIO_Port GPIOA
#define USART2_TX_Pin GPIO_PIN_2
#define USART2_TX_GPIO_Port GPIOA
#define TIM3_CH1_Pin GPIO_PIN_6
#define TIM3_CH1_GPIO_Port GPIOA
#define USART1_TX_Pin GPIO_PIN_4
#define USART1_TX_GPIO_Port GPIOC
#define USART1_RX_Pin GPIO_PIN_5
#define USART1_RX_GPIO_Port GPIOC
#define USART3_TX_Pin GPIO_PIN_10
#define USART3_TX_GPIO_Port GPIOB
#define USART3_RX_Pin GPIO_PIN_11
#define USART3_RX_GPIO_Port GPIOB
#define SPI_DC_Pin GPIO_PIN_6
#define SPI_DC_GPIO_Port GPIOC
#define SPI_RST_Pin GPIO_PIN_7
#define SPI_RST_GPIO_Port GPIOC
#define SPI_CS_Pin GPIO_PIN_8
#define SPI_CS_GPIO_Port GPIOC
#define UART4_TX_Pin GPIO_PIN_10
#define UART4_TX_GPIO_Port GPIOC
#define UART4_RX_Pin GPIO_PIN_11
#define UART4_RX_GPIO_Port GPIOC
#define LED1_Pin GPIO_PIN_4
#define LED1_GPIO_Port GPIOB
#define LED2_Pin GPIO_PIN_5
#define LED2_GPIO_Port GPIOB
#define LED3_Pin GPIO_PIN_6
#define LED3_GPIO_Port GPIOB

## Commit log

2025-03-13 started schematic for pcbs
    [PCB_main_unit.kicad_pcb, PCB_main_unit.kicad_sch]
2025-03-13 finished main unit schematic
    [PCB_main_unit.kicad_sch]
2025-03-15 started controller PCB
    [PCB_controller.kicad_pcb, PCB_controller.kicad_sch, PCB_main_unit.kicad_sch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]
2025-03-15 finished controller pcb
    [PCB_controller.kicad_sch, untitled.kicad_sch]
2025-03-15 started main unit PCB
    [PCB_main_unit.kicad_pcb, PCB_main_unit.kicad_sch]
2025-03-15 j'ai rien a dire
    [PCB_main_unit.kicad_pcb]
2025-03-16 finished main unit PCB
    [PCB_main_unit.kicad_pcb]
2025-03-20 minor changes
    [PCB_main_unit.kicad_pcb]
2025-03-20 review sch
    [PCB_main_unit.kicad_sch]
2025-03-20 applied changes
    [PCB_controller.kicad_pcb, PCB_controller.kicad_sch, PCB_main_unit.kicad_pcb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]
2025-03-20 generated gerbers and drill files
    [PCB_main_unit-B_Cu.gbr, PCB_main_unit-B_Mask.gbr, PCB_main_unit-B_Paste.gbr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]
2025-03-23 update pcb
    [PCB_main_unit-B_Cu.gbr, PCB_main_unit-B_Mask.gbr, PCB_main_unit-B_Paste.gbr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]
2025-03-23 export gerbers
    [PCB_controller-B_Cu.gbr, PCB_controller-B_Mask.gbr, PCB_controller-B_Paste.gbr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]
2025-04-19 added CAD models of the projects
    [bed.stl, chair.stl, door_1.stl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]

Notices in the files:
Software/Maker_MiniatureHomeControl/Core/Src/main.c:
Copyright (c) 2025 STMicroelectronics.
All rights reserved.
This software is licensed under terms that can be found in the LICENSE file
